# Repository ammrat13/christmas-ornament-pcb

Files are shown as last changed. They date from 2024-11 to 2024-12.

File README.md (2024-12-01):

# EE 256 Final Project: Christmas Ornament

Board files and firmware for my final project for EE 256. I made a relatively
simple project - just a smart christmas ornament.

  * Low-light conditions turn on the LEDs
  * Shaking the ornament flashes the NeoPixels
  * Thresholds and flash parameters configurable via micro-SD card
  * Sensor values, activation statistics, and device health visible over
    Bluetooth LE
  * Supports LiIon batteries
  * Watchdog timer for reliability

## Block Diagram

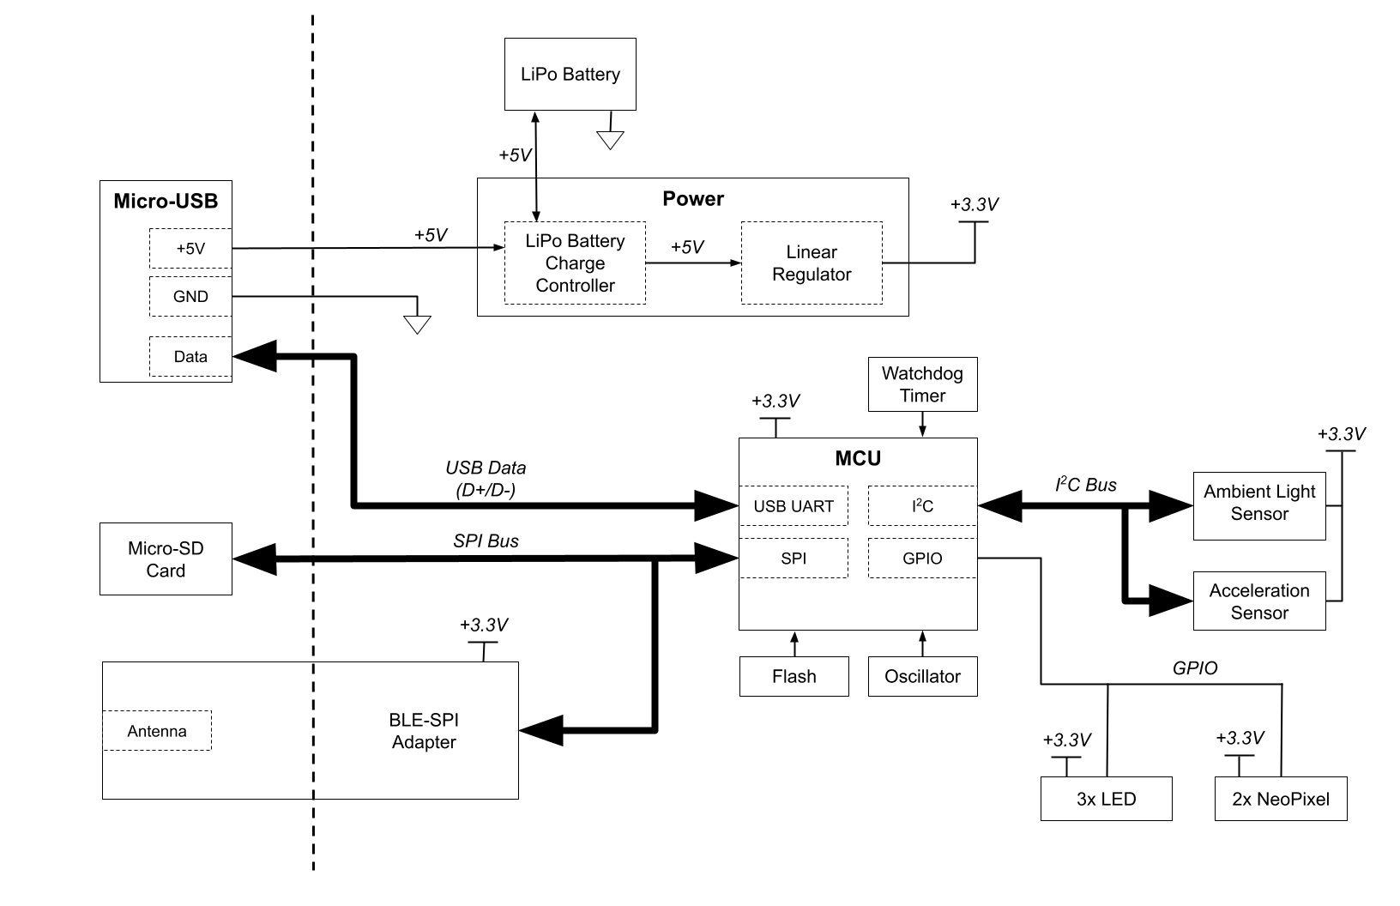
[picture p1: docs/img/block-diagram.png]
Block Diagram


## Project Structure
  * `firmware`: code for the MCU
  * `host`: code to communicate with the MCU over Bluetooth LE
  * `kicad`: board files
  * `kicad-lib`: global library files referenced by the board files

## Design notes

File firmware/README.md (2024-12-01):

# Device Firmware

This folder has the CircuitPython firmware for the device. It contains a
`Pipfile` for installing `circup` on the host, as well as a `requirements.txt`
for getting the required libraries onto the device.

To save on space, all the files (except for `code.py`) are compiled. Download
`mpy-cross` and set the `MPY_CROSS` environment variable to that path. If more
files are added, modify `PY_FILES` in the `Makefile` with the new code. Finally,
mount the device at some path `${DEVICE_PATH}` and run
```
$ make all
$ make PREFIX="${DEVICE_PATH}" install
```

## Configuration Files

An example configuration file is given in `config.txt`. It should be placed at
the root of the micro-SD card. Additionally, if a file named `reset-ble` is
present on the root of the micro-SD card, then the Bluefruit LE SPI friend will
be factory-reset and repopulated.

## Register Map

Over Bluetooth LE, this firmware provides a service with some characteristics,
which act as MMIO registers. The registers are defined in `ble.py` as `CHAR_*`.
The service's UUID is given as `SERVICE_UUID`.

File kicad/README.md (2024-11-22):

# PCB Files

This folder has the KiCad files for the PCBs fabricated. The ADXL 343 Adapter
and Revision 1 of the Project were fabricated. The files in the `kicad-lib`
folder may be needed to edit these files.

## Errata

### Project Revision 1
  * Q1 uses the incorrect footprint. They should be rotated 120 degrees
    counter-clockwise.
  * D2 and D3 don't have decoupling capacitors. They should have 1uF capacitors.
  * D2 doesn't have a decoupling resistor on the data line. It should have a
    470R on the input.

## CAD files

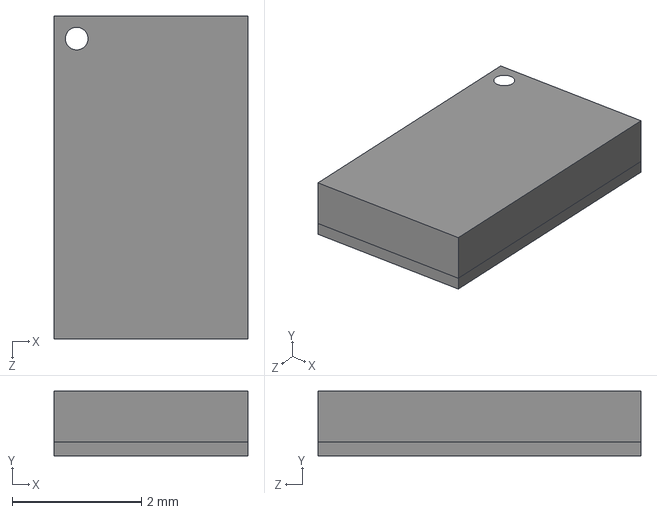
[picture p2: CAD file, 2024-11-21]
kicad/ADXL 343 Adapter/ADXL343BCCZ-RL7.step
3.00 x 1.00 x 5.00 mm

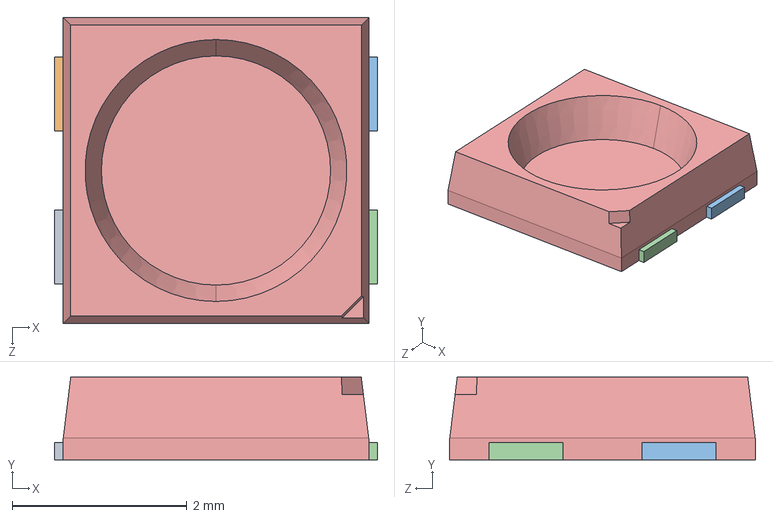
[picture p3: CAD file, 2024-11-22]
kicad/Project/rev2/Components/2659.step
3.70 x 0.95 x 3.50 mm

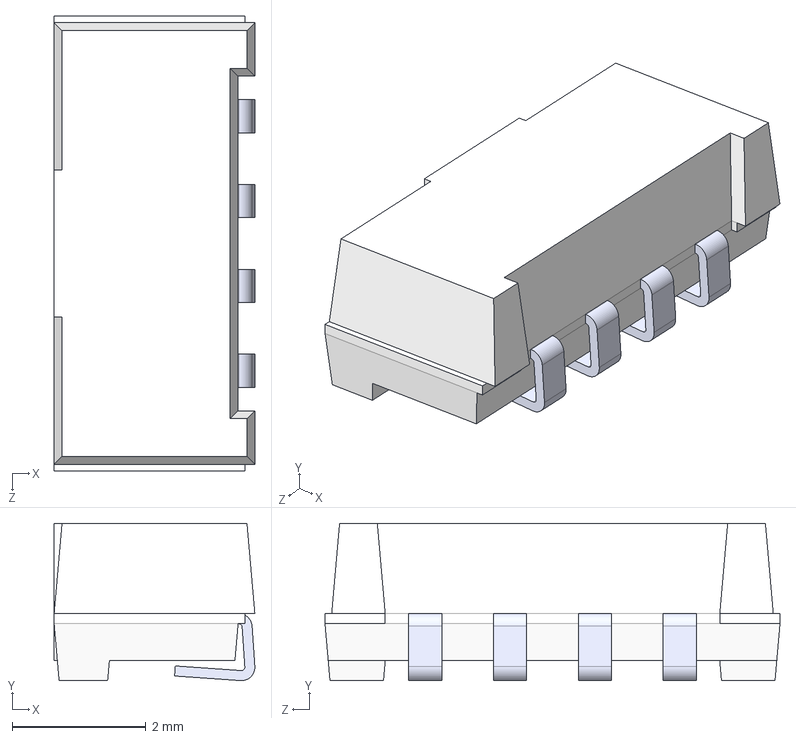
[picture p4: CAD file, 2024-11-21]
kicad/Project/rev2/Components/VEML7700-TR.step
3.00 x 2.35 x 6.80 mm

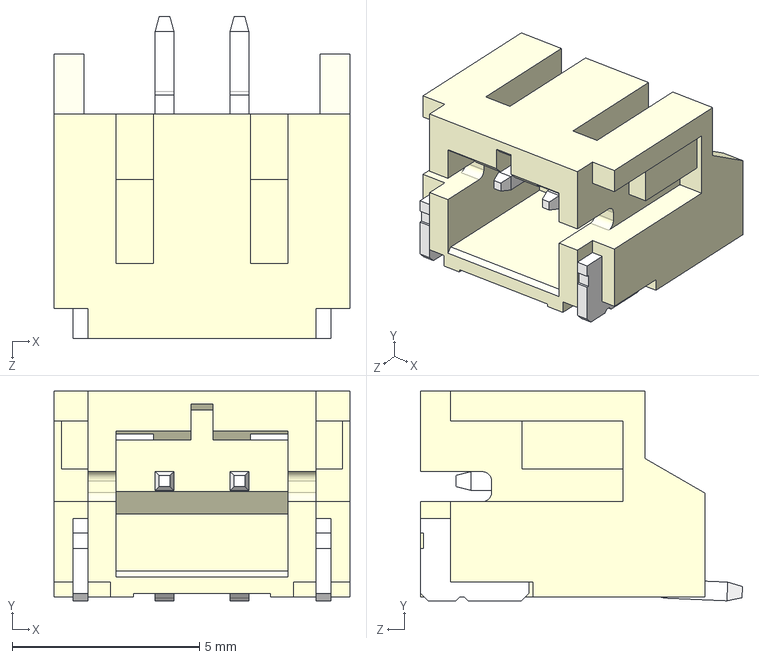
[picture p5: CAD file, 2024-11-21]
kicad/Project/rev2/Components/S2B-PH-SM4-TB.step
7.90 x 5.60 x 8.60 mm

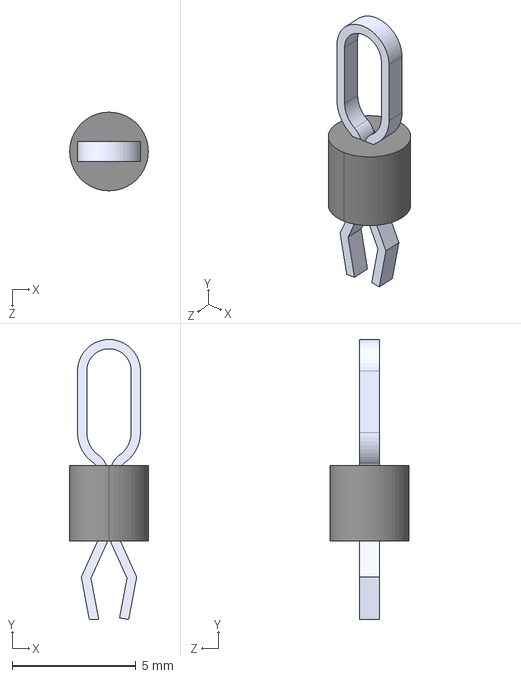
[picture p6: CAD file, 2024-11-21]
kicad/Project/rev2/Components/5011.step
3.17 x 11.3 x 3.17 mm

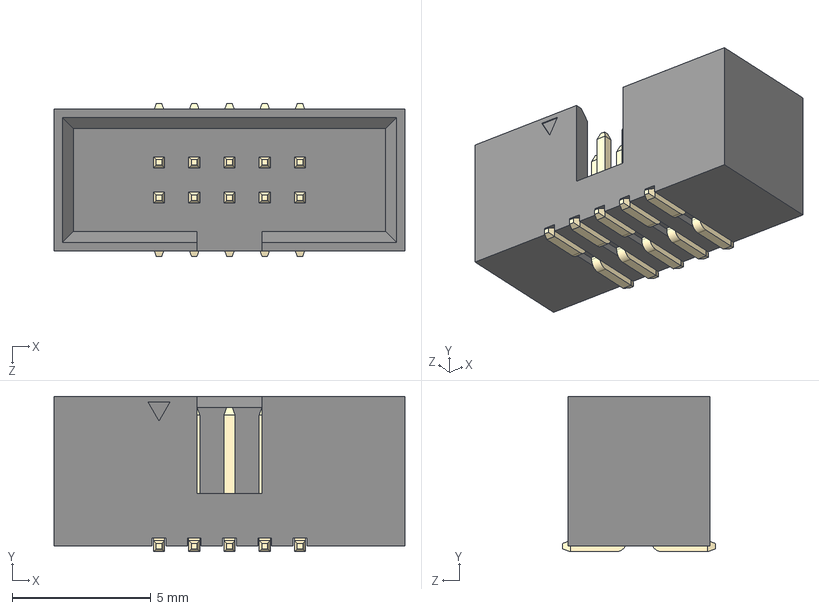
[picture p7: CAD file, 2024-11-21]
kicad/Project/rev2/Components/3220-10-0300-00.step
12.7 x 5.60 x 5.50 mm
3220-xx-0300-00 body_10
Pin^3220-xx-0300-00 x 5
MirrorPin^3220-xx-0300-00 x 5

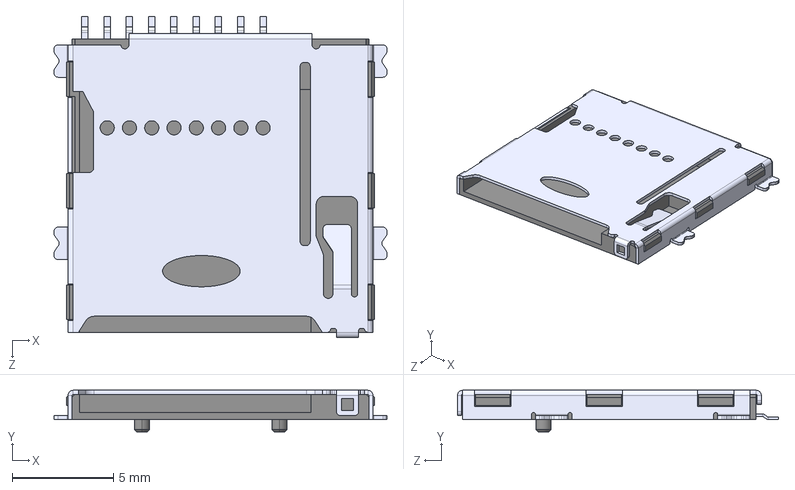
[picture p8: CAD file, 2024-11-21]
kicad/Project/rev2/Components/MEM2075-00-140-01-A.step
16.4 x 2.05 x 15.9 mm

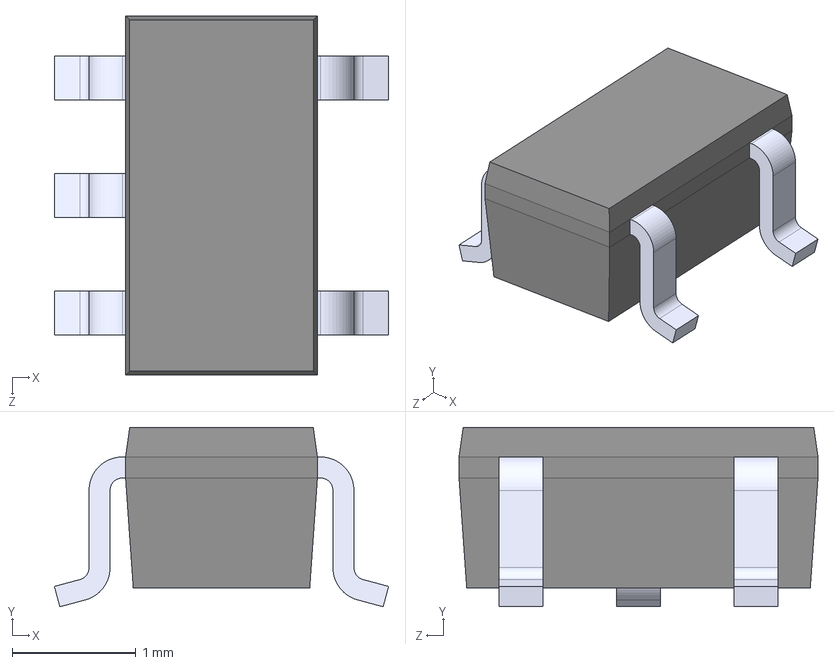
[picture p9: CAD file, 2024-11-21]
kicad/Project/rev2/Components/MCP73831T-2ATI_OT.step
2.70 x 1.45 x 2.90 mm

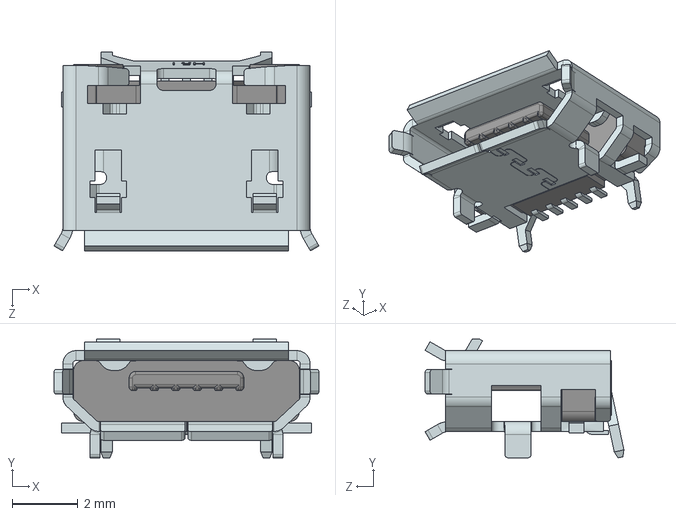
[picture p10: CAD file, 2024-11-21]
kicad/Project/rev2/Components/10103594-0001LF.step
8.04 x 3.60 x 6.03 mm

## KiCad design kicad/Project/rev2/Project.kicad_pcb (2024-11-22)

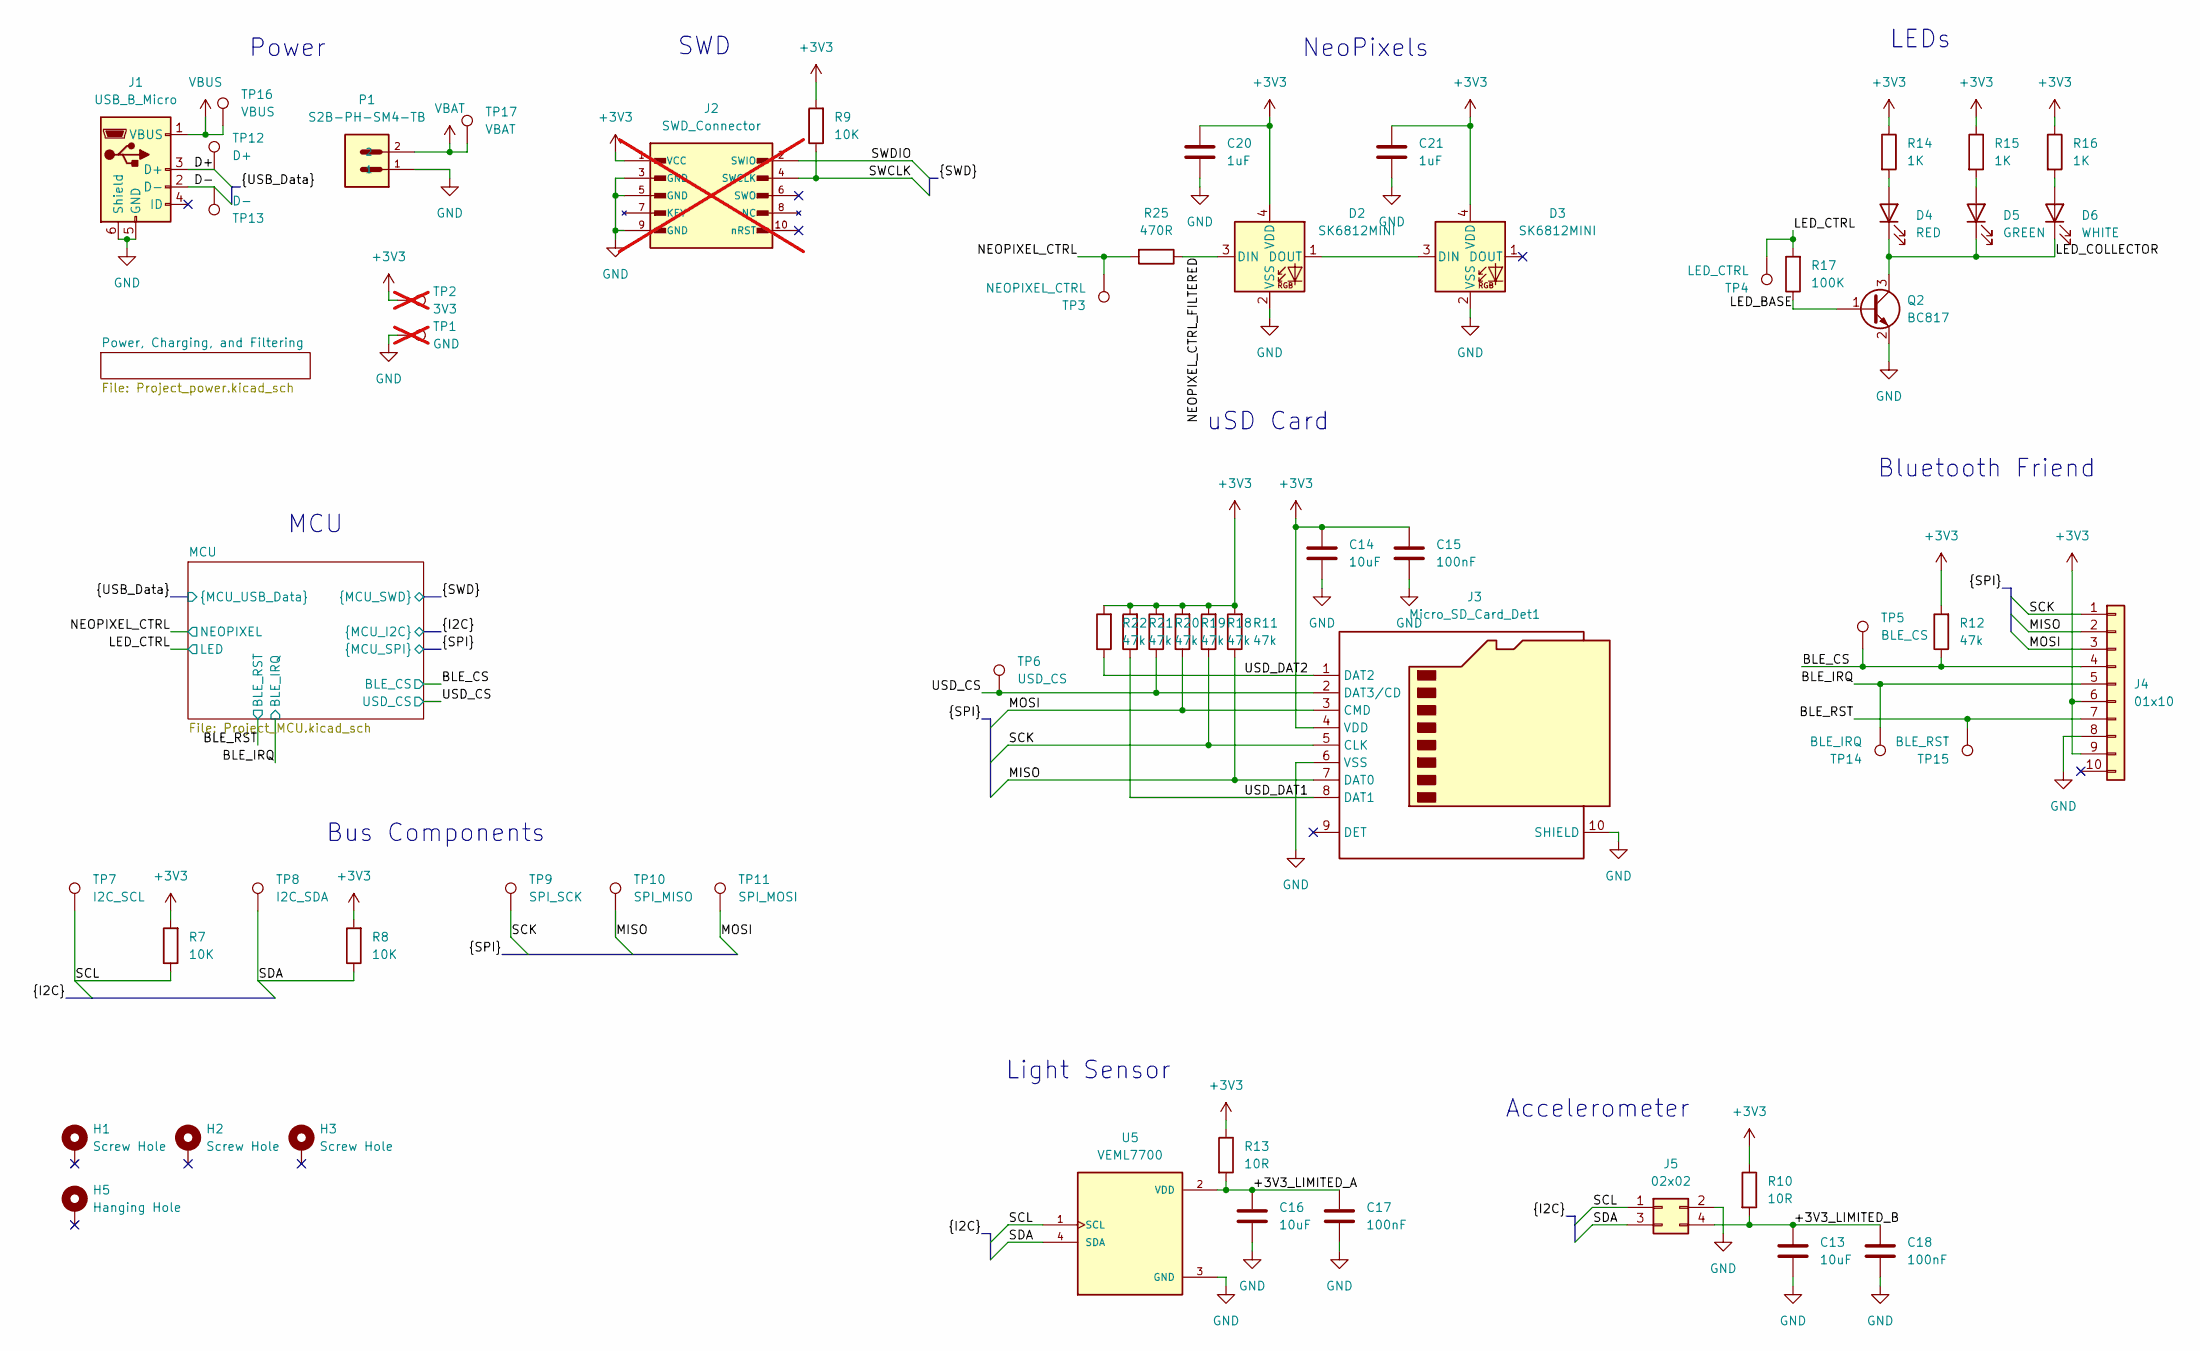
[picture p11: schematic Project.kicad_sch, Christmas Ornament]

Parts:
C13, C14, C16: 10uF; C_0805_2012Metric_Pad1.18x1.45mm_HandSolder; Mfr P/N CL21A106KOQNNNE
C15, C17, C18: 100nF; C_0402_1005Metric_Pad0.74x0.62mm_HandSolder; Mfr P/N CL05B104KP5NNNC
C20, C21: 1uF; C_0603_1608Metric_Pad1.08x0.95mm_HandSolder; Mfr P/N CC0603KRX7R7BB105
D2, D3: SK6812MINI; LED_SK6812MINI_PLCC4_3.5x3.5mm_P1.75mm; Mfr P/N 2659
D4: RED; LED_0805_2012Metric_Pad1.15x1.40mm_HandSolder; Mfr P/N LTST-S220KRKT
D5: GREEN; LED_0805_2012Metric_Pad1.15x1.40mm_HandSolder; Mfr P/N LTST-S220KGKT
D6: WHITE; LED_0805_2012Metric_Pad1.15x1.40mm_HandSolder; Mfr P/N LTW-170TK
H1, H2, H3: Screw Hole; MountingHole_3.2mm_M3_DIN965_Pad_TopBottom
H5: Hanging Hole; MountingHole_3.2mm_M3_DIN965_Pad_TopBottom
J1: USB_B_Micro; USB_Micro-B_Amphenol_10103594-0001LF_Horizontal; Mfr P/N 10103594-0001LF
J2: SWD_Connector; CNC_3220-10-0300-00; Mfr P/N 3220-10-0300-00; not fitted
J3: Micro_SD_Card_Det1; GCT_MEM2075-00-140-01-A; Mfr P/N MEM2075-00-140-01-A
J4: 01x10; PinSocket_1x10_P2.54mm_Vertical; Mfr P/N PPTC101LFBN-RC
J5: 02x02; PinSocket_2x02_P2.54mm_Vertical; Mfr P/N PPPC022LFBN-RC
P1: S2B-PH-SM4-TB; JST_PH_S2B-PH-SM4-TB_1x02-1MP_P2.00mm_Horizontal; Mfr P/N S2B-PH-SM4-TB
Q2: BC817; SOT-23; Mfr P/N BC817-25LT1G
R7, R8, R9: 10K; R_0603_1608Metric_Pad0.98x0.95mm_HandSolder; Mfr P/N RNCP0603FTD10K0
R10, R13: 10R; R_0603_1608Metric_Pad0.98x0.95mm_HandSolder; Mfr P/N RMCF0603FT10R0
R11, R12, R18, R19, R20, R21, R22: 47k; R_0603_1608Metric_Pad0.98x0.95mm_HandSolder; Mfr P/N RC0603FR-0747KL
R14, R15, R16: 1K; R_0603_1608Metric_Pad0.98x0.95mm_HandSolder; Mfr P/N MCT06030C1001FP500
R17: 100K; R_0603_1608Metric_Pad0.98x0.95mm_HandSolder; Mfr P/N RMCF0603FT100K
R25: 470R; R_0603_1608Metric_Pad0.98x0.95mm_HandSolder; Mfr P/N RC0603JR-07470RL
TP1: GND; TP_5011; Mfr P/N 5011; not fitted
TP2: 3V3; TP_5011; Mfr P/N 5010; not fitted
TP3: NEOPIXEL_CTRL; TestPoint_Pad_D2.0mm
TP4: LED_CTRL; TestPoint_Pad_D2.0mm
TP5: BLE_CS; TestPoint_Pad_D2.0mm
TP6: USD_CS; TestPoint_Pad_D2.0mm
TP7: I2C_SCL; TestPoint_Pad_D2.0mm
TP8: I2C_SDA; TestPoint_Pad_D2.0mm
TP9: SPI_SCK; TestPoint_Pad_D2.0mm
TP10: SPI_MISO; TestPoint_Pad_D2.0mm
TP11: SPI_MOSI; TestPoint_Pad_D2.0mm
TP12: D+; TestPoint_Pad_D2.0mm
TP13: D-; TestPoint_Pad_D2.0mm
TP14: BLE_IRQ; TestPoint_Pad_D2.0mm
TP15: BLE_RST; TestPoint_Pad_D2.0mm
TP16: VBUS; TestPoint_Pad_D2.0mm
TP17: VBAT; TestPoint_Pad_D2.0mm
U5: VEML7700; XDCR_VEML7700-TR; Mfr P/N VEML7700-TR

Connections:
+3V3: C14.1, C15.1, C20.1, C21.1, D2.4 (VDD), D3.4 (VDD), J2.1 (VCC), J3.4 (VDD), J4.6, J4.9, R7.2, R8.2, R9.2, R10.1, R11.2, R12.2, R13.1, R14.1, R15.1, R16.1, R18.2, R19.2, R20.2, R21.2, R22.2, TP2.1; also elsewhere on the board
/+3V3_LIMITED_A: C16.1, C17.1, R13.2, U5.2 (VDD)
/+3V3_LIMITED_B: C13.1, C18.1, J5.4, R10.2
/BLE_CS: J4.4, R12.1, TP5.1; also elsewhere on the board
/BLE_IRQ: J4.5, TP14.1; also elsewhere on the board
/BLE_RST: J4.7, TP15.1; also elsewhere on the board
/D+: J1.3 (D+), TP12.1; also elsewhere on the board
/D-: J1.2 (D-), TP13.1; also elsewhere on the board
/LED_BASE: Q2.1 (B), R17.1
/LED_COLLECTOR: D4.1 (K), D5.1 (K), D6.1 (K), Q2.3 (C)
/LED_CTRL: R17.2, TP4.1; also elsewhere on the board
/MISO: J3.7 (DAT0), J4.2, R11.1, TP10.1; also elsewhere on the board
/MOSI: J3.3 (CMD), J4.3, R19.1, TP11.1; also elsewhere on the board
/NEOPIXEL_CTRL: R25.2, TP3.1; also elsewhere on the board
/NEOPIXEL_CTRL_FILTERED: D2.3 (DIN), R25.1
/SCK: J3.5 (CLK), J4.1, R18.1, TP9.1; also elsewhere on the board
/SCL: J5.1, R7.1, TP7.1, U5.1 (SCL); also elsewhere on the board
/SDA: J5.3, R8.1, TP8.1, U5.4 (SDA); also elsewhere on the board
/SWCLK: J2.4 (SWCLK), R9.1; also elsewhere on the board
/SWDIO: J2.2 (SWIO); also elsewhere on the board
/USD_CS: J3.2 (DAT3/CD), R20.1, TP6.1; also elsewhere on the board
/USD_DAT1: J3.8 (DAT1), R21.1
/USD_DAT2: J3.1 (DAT2), R22.1
GND: C13.2, C14.2, C15.2, C16.2, C17.2, C18.2, C20.2, C21.2, D2.2 (VSS), D3.2 (VSS), J1.5 (GND), J1.6 (Shield), J2.3 (GND), J2.5 (GND), J2.9 (GND), J3.6 (VSS), J3.10 (SHIELD), J4.8, J5.2, P1.1, Q2.2 (E), TP1.1, U5.3 (GND); also elsewhere on the board
unnamed: D2.1 (DOUT), D3.3 (DIN)
unnamed: D4.2 (A), R14.2
unnamed: D5.2 (A), R15.2
unnamed: D6.2 (A), R16.2
VBAT: P1.2, TP17.1; also elsewhere on the board
VBUS: J1.1 (VBUS), TP16.1; also elsewhere on the board

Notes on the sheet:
MCU
Accelerometer
Bus Components
Bluetooth Friend
SWD
Light Sensor
NeoPixels
uSD Card
LEDs
Power

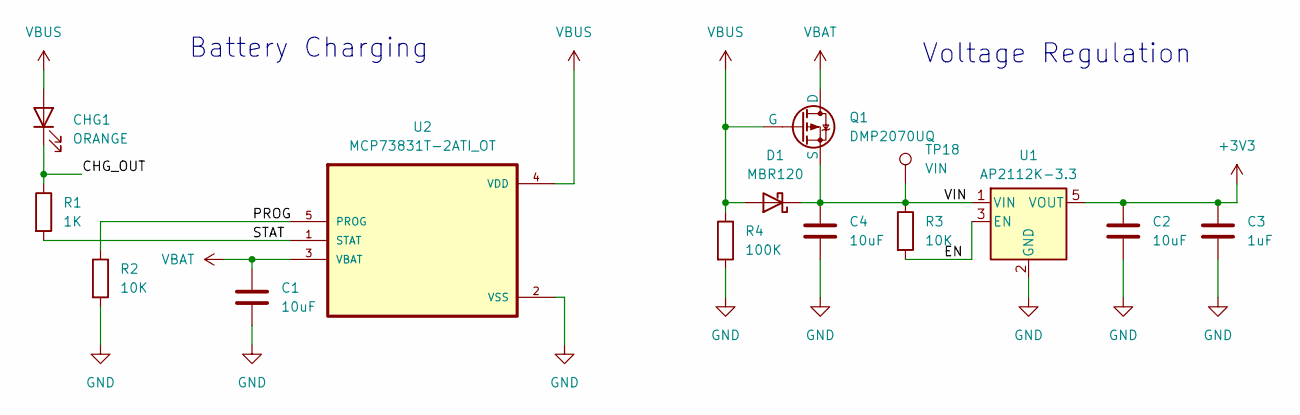
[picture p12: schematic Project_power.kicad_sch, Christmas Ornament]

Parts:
C1, C2, C4: 10uF; C_0805_2012Metric_Pad1.18x1.45mm_HandSolder; Mfr P/N CL21A106KOQNNNE
C3: 1uF; C_0603_1608Metric_Pad1.08x0.95mm_HandSolder; Mfr P/N CC0603KRX7R7BB105
CHG1: ORANGE; LED_0805_2012Metric_Pad1.15x1.40mm_HandSolder; Mfr P/N B1701UD--20D000414U1930
D1: MBR120; D_SOD-123; Mfr P/N MBR120LSFT1G
Q1: DMP2070UQ; SOT-23_Handsoldering
R1: 1K; R_0603_1608Metric_Pad0.98x0.95mm_HandSolder; Mfr P/N MCT06030C1001FP500
R2, R3: 10K; R_0603_1608Metric_Pad0.98x0.95mm_HandSolder; Mfr P/N RNCP0603FTD10K0
R4: 100K; R_0603_1608Metric_Pad0.98x0.95mm_HandSolder; Mfr P/N RMCF0603FT100K
TP18: VIN; TestPoint_Pad_D2.0mm
U1: AP2112K-3.3; SOT-23-5
U2: MCP73831T-2ATI_OT; SOT-23-5_HandSoldering; Mfr P/N MCP73831T-2ATI/OT

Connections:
+3V3: C2.1, C3.1, U1.5 (VOUT); also elsewhere on the board
/Power, Charging, and Filtering/CHG_OUT: CHG1.1 (K), R1.1
/Power, Charging, and Filtering/EN: R3.2, U1.3 (EN)
/Power, Charging, and Filtering/PROG: R2.1, U2.5 (PROG)
/Power, Charging, and Filtering/STAT: R1.2, U2.1 (STAT)
/Power, Charging, and Filtering/VIN: C4.1, D1.1 (K), Q1.2 (S), R3.1, TP18.1, U1.1 (VIN)
GND: C1.2, C2.2, C3.2, C4.2, R2.2, R4.2, U1.2 (GND), U2.2 (VSS); also elsewhere on the board
VBAT: C1.1, Q1.3 (D), U2.3 (VBAT); also elsewhere on the board
VBUS: CHG1.2 (A), D1.2 (A), Q1.1 (G), R4.1, U2.4 (VDD); also elsewhere on the board

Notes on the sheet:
Battery Charging
Voltage Regulation

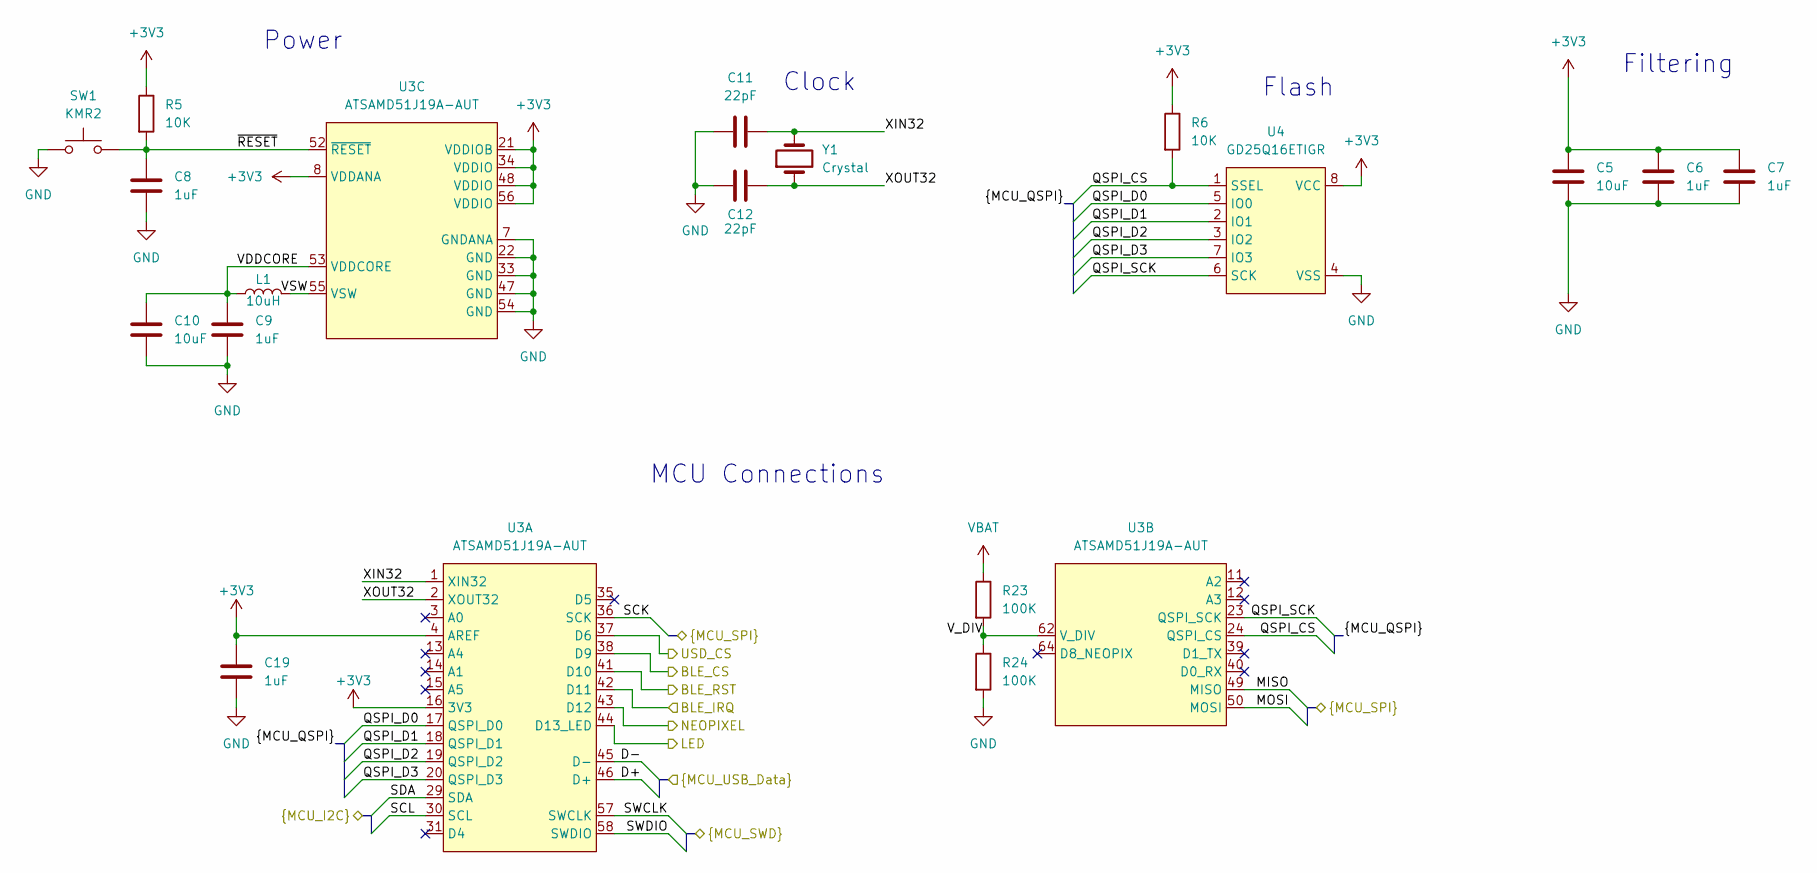
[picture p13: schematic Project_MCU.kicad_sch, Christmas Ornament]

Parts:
C5, C10: 10uF; C_0805_2012Metric_Pad1.18x1.45mm_HandSolder; Mfr P/N CL21A106KOQNNNE
C6, C7, C8, C9, C19: 1uF; C_0603_1608Metric_Pad1.08x0.95mm_HandSolder; Mfr P/N CC0603KRX7R7BB105
C11, C12: 22pF; C_0603_1608Metric_Pad1.08x0.95mm_HandSolder; Mfr P/N C0603C220K4GAC7867
L1: 10uH; L_1008_2520Metric; Mfr P/N LSQEA251818T100K
R5, R6: 10K; R_0603_1608Metric_Pad0.98x0.95mm_HandSolder; Mfr P/N RNCP0603FTD10K0
R23, R24: 100K; R_0603_1608Metric_Pad0.98x0.95mm_HandSolder; Mfr P/N RMCF0603FT100K
SW1: KMR2; SW_Push_1P1T_NO_CK_KMR2; Mfr P/N KMR241NG ULC LFS
U3: ATSAMD51J19A-AUT; TQFP-64_10x10mm_P0.5mm; Mfr P/N ATSAMD51J19A-AUT
U4: GD25Q16ETIGR; SOIC-8_3.9x4.9mm_P1.27mm; Mfr P/N GD25Q16ETIGR
Y1: Crystal; XTAL3215; Mfr P/N STDMUA17-32.768K

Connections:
+3V3: C5.1, C6.1, C7.1, C19.1, R5.1, R6.1, U3.4 (AREF), U3.8 (VDDANA), U3.16 (3V3), U3.21 (VDDIOB), U3.34 (VDDIO), U3.48 (VDDIO), U3.56 (VDDIO), U4.8 (VCC); also elsewhere on the board
/BLE_CS: U3.38 (D9); also elsewhere on the board
/BLE_IRQ: U3.42 (D11); also elsewhere on the board
/BLE_RST: U3.41 (D10); also elsewhere on the board
/D+: U3.46 (D+); also elsewhere on the board
/D-: U3.45 (D-); also elsewhere on the board
/LED_CTRL: U3.44 (D13_LED); also elsewhere on the board
/MCU/QSPI_CS: R6.2, U3.24 (QSPI_CS), U4.1 (SSEL)
/MCU/QSPI_D0: U3.17 (QSPI_D0), U4.5 (IO0)
/MCU/QSPI_D1: U3.18 (QSPI_D1), U4.2 (IO1)
/MCU/QSPI_D2: U3.19 (QSPI_D2), U4.3 (IO2)
/MCU/QSPI_D3: U3.20 (QSPI_D3), U4.7 (IO3)
/MCU/QSPI_SCK: U3.23 (QSPI_SCK), U4.6 (SCK)
/MCU/VDDCORE: C9.1, C10.1, L1.1, U3.53 (VDDCORE)
/MCU/VSW: L1.2, U3.55 (VSW)
/MCU/V_DIV: R23.2, R24.1, U3.62 (V_DIV)
/MCU/XIN32: C11.1, U3.1 (XIN32), Y1.2
/MCU/XOUT32: C12.1, U3.2 (XOUT32), Y1.1
/MCU/~RESET: C8.1, R5.2, SW1.2, U3.52 (~RESET)
/MISO: U3.49 (MISO); also elsewhere on the board
/MOSI: U3.50 (MOSI); also elsewhere on the board
/NEOPIXEL_CTRL: U3.43 (D12); also elsewhere on the board
/SCK: U3.36 (SCK); also elsewhere on the board
/SCL: U3.30 (SCL); also elsewhere on the board
/SDA: U3.29 (SDA); also elsewhere on the board
/SWCLK: U3.57 (SWCLK); also elsewhere on the board
/SWDIO: U3.58 (SWDIO); also elsewhere on the board
/USD_CS: U3.37 (D6); also elsewhere on the board
GND: C5.2, C6.2, C7.2, C8.2, C9.2, C10.2, C11.2, C12.2, C19.2, R24.2, SW1.1, U3.7 (GNDANA), U3.22 (GND), U3.33 (GND), U3.47 (GND), U3.54 (GND), U4.4 (VSS); also elsewhere on the board
VBAT: R23.1; also elsewhere on the board

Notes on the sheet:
Power
Filtering
Clock
MCU Connections
Flash

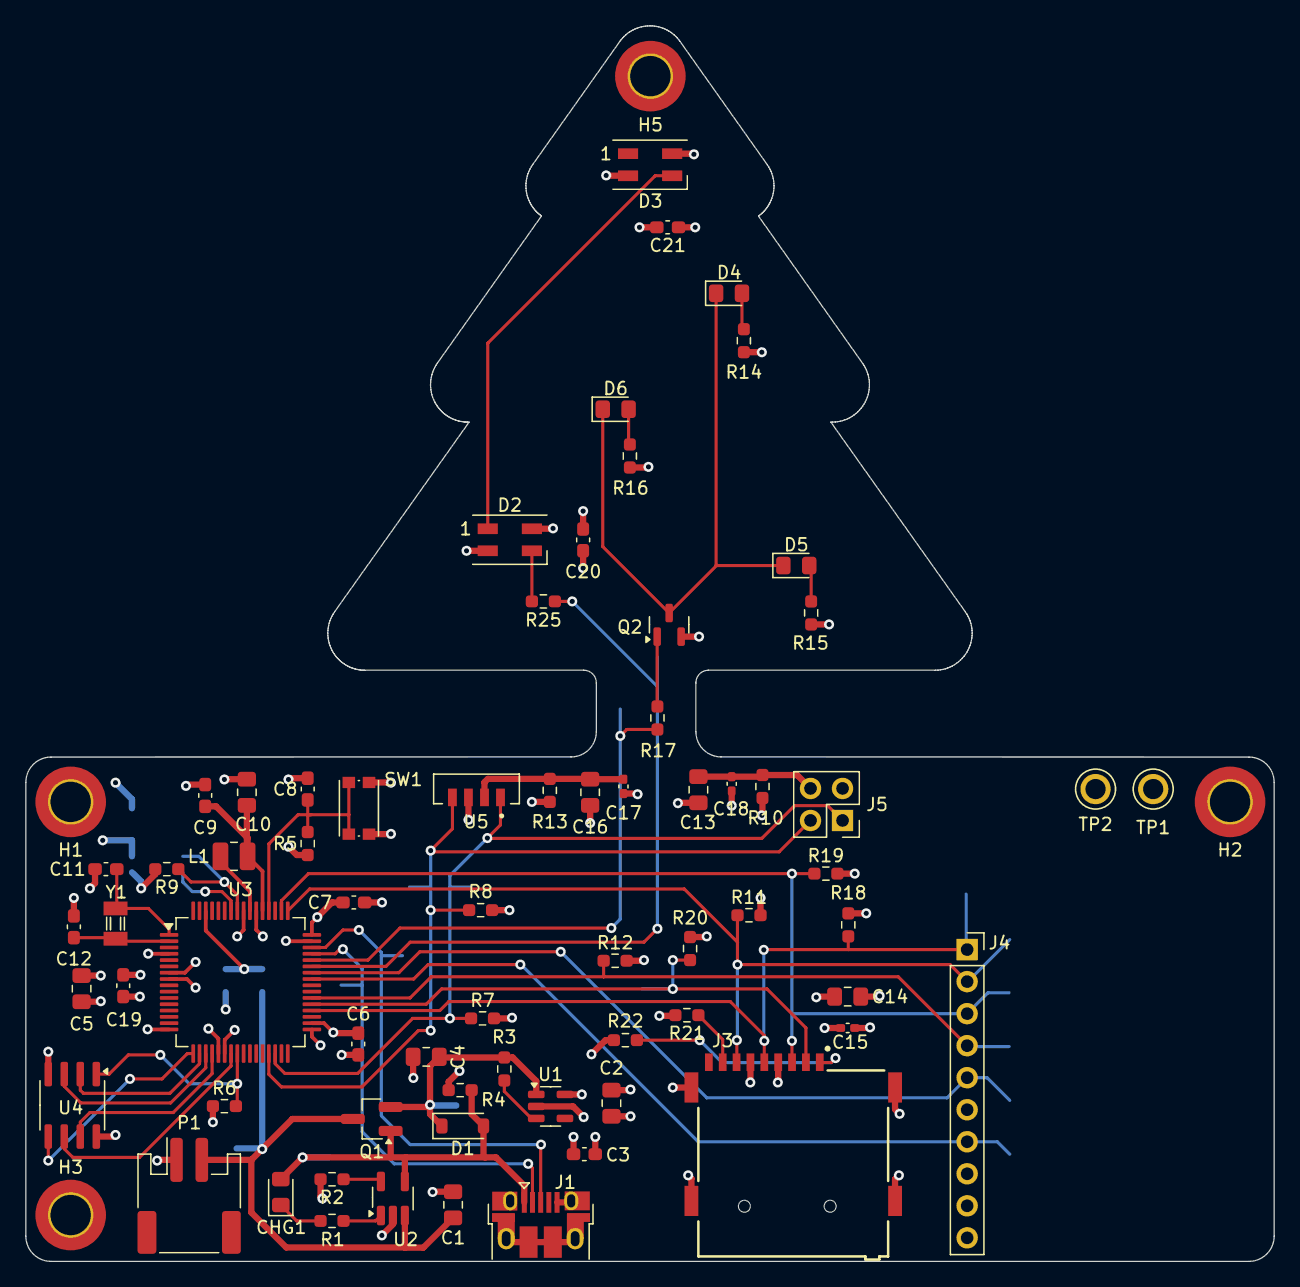
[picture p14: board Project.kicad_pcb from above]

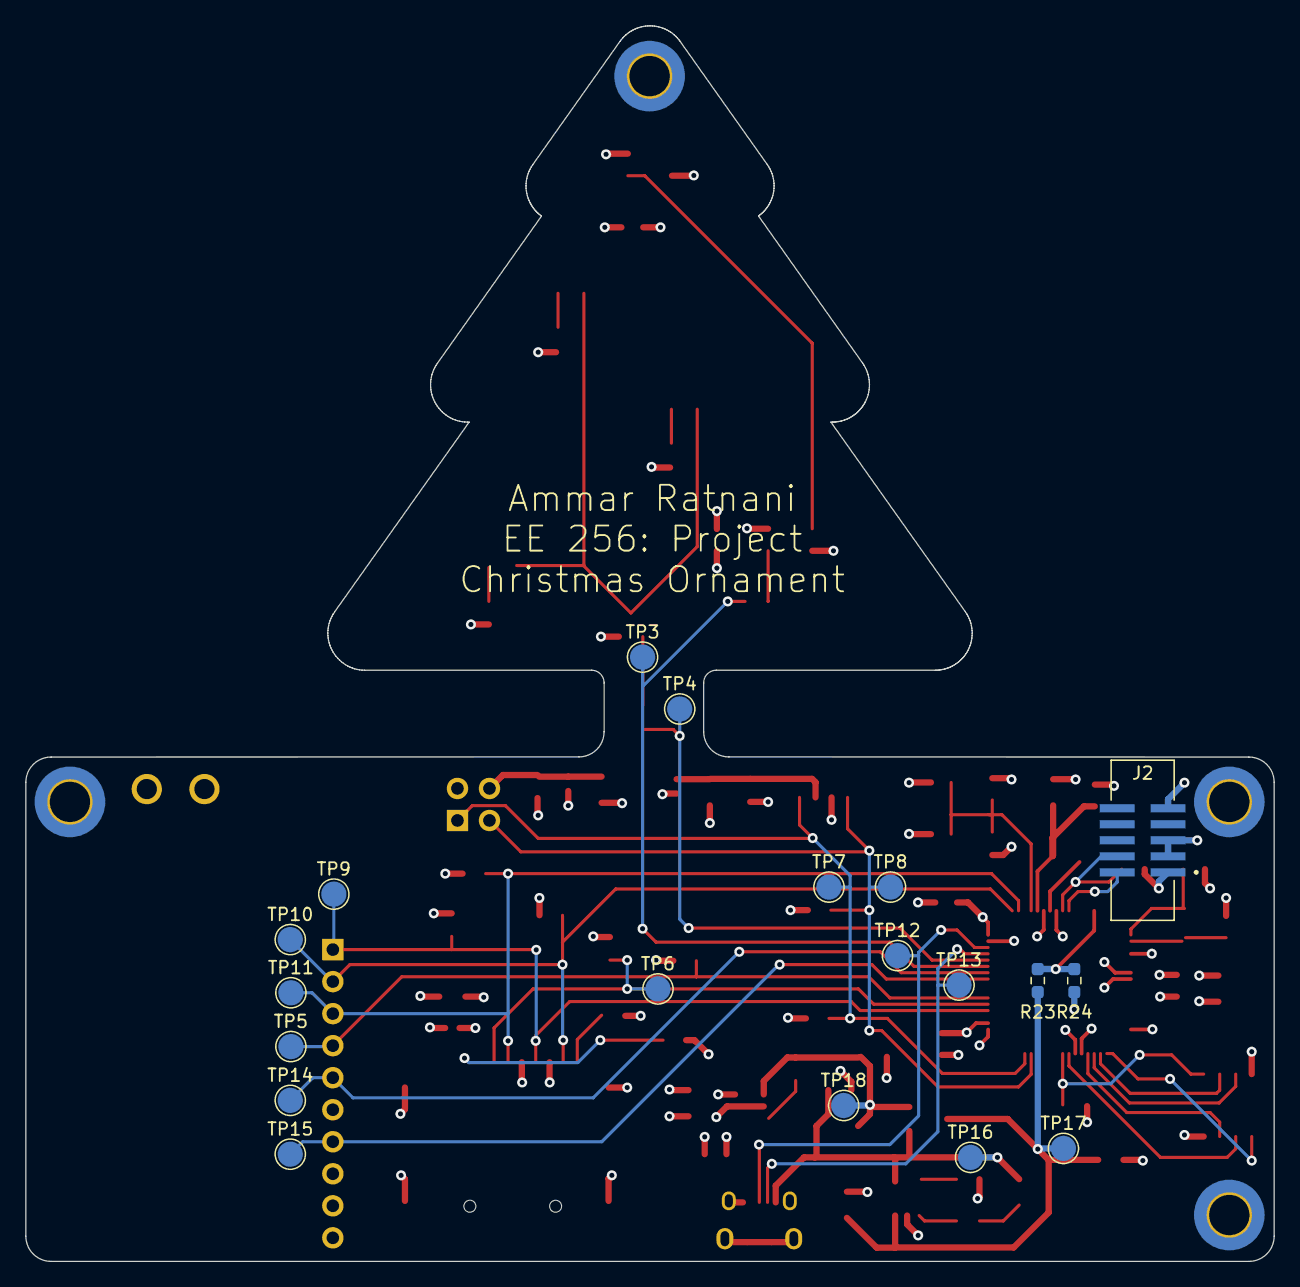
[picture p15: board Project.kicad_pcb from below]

Board: 4 copper layers, 99.0 x 98.0 mm, 91 parts (19 on the bottom side), 47 nets.

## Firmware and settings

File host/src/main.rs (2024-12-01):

mod attrs;
mod ble;

use std::time::Duration;

use anyhow::{Context, Error, Result};
use argparse::ArgumentParser;
use btleplug::api::Peripheral as _;
use btleplug::platform::Peripheral;
use tokio::net::TcpListener;
use tokio::task::JoinSet;

use attrs::ApplicationState;

#[tokio::main]
async fn main() -> Result<()> {
    env_logger::init();

    let mut local_name = String::from("Christmas Ornament");
    let mut scan_time_s = 15u64;
    let mut disconnect_poll_s = 1u64;
    let mut port = 3000u16;
    {
        let mut ap = ArgumentParser::new();
        ap.set_description("Interface with the Christmas ornament over BLE");
        ap.refer(&mut scan_time_s).metavar("SCAN_TIME").add_option(
            &["-t", "--scan-time"],
            argparse::Store,
            "Time to scan for peripherals for, in seconds",
        );
        ap.refer(&mut disconnect_poll_s)
            .metavar("DISCONNECT_POLL_INTERVAL")
            .add_option(
                &["-d", "--disconnect-poll"],
                argparse::Store,
                "Time to poll for the ornament disconnecting, in seconds",
            );
        ap.refer(&mut port).metavar("PORT").add_option(
            &["-p", "--port"],
            argparse::Store,
            "Port to listen on for HTTP requests",
        );
        ap.refer(&mut local_name)
            .metavar("LOCAL_NAME")
            .required()
            .add_argument(
                "local_name",
                argparse::Store,
                "Display name of the ornament",
            );
        ap.parse_args_or_exit();
    }

    let scan_duration = Duration::from_secs(scan_time_s);
    let poll_duration = Duration::from_secs(disconnect_poll_s);

    let peripheral = ble::connect(&local_name, scan_duration).await?;
    let service = ble::get_service(&peripheral)?;

    let app = attrs::router().with_state(ApplicationState {
        peripheral: peripheral.clone(),
        service: service.clone(),
    });

    let listener = TcpListener::bind(("0.0.0.0", port)).await.unwrap();

    let mut joinset = JoinSet::new();
    joinset.spawn(async { axum::serve(listener, app).await.context("Server died") });
    joinset.spawn(disconnect_handler(peripheral.clone(), poll_duration));

    while let Some(r) = joinset.join_next().await {
        let r = match r {
            Ok(r) => r,
            Err(e) => anyhow::bail!("{:?}", e),
        };
        match r {
            Ok(()) => anyhow::bail!("Some task finished when it was supposed to run forever"),
            Err(e) => anyhow::bail!("{:?}", e),
        }
    }

    // We should always pop some result, so this is unreachable
    unreachable!();
}

/// What to do when the peripheral disconnects from us. We'll poll this every
/// second, and cause an error if that happens.
async fn disconnect_handler(peripheral: Peripheral, poll_interval: Duration) -> Result<(), Error> {
    loop {
        tokio::time::sleep(poll_interval).await;
        if peripheral.is_connected().await? {
            continue;
        }
        anyhow::bail!("Peripheral disconnected");
    }
}

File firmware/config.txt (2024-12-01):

################################################################################
#
# Sample configuration file.
#
# Save this as `config.txt` on the root of the micro-SD card.
#
################################################################################

# Name of the device, as shown in Bluetooth scans. Only has an effect once the
# Bluefruit LE SPI module is reset.
DEVICE_NAME = Ammar Ratnani EE 256

# The light level below which the LEDs will be turned on, in lux
LIGHT_THRESHOLD = 30.0
# The exponential moving average factor for the light sensor
LIGHT_MOVING_AVG = 0.8

# The acceleration threshold for detecting acceleration, in g
ACCELERATION_THRESHOLD = 6.25

# The brightness of the NeoPixels when they are flashing, from 0 to 255
NEOPIXEL_BRIGHTNESS = 5
# The time in seconds for the NeoPixels to flash
NEOPIXEL_FLASH_TIME = 1.0
# The number of seconds to wait between frames of flashing
NEOPIXEL_FLASH_SPEED = 0.1

# The time in seconds before the watchdog will reset the device
WATCHDOG_TIMEOUT = 10.0
# The time in seconds between watchdog pets. The task to perform the pet will
# become available after this time, but it may not be run immediately.
WATCHDOG_PET_INTERVAL = 5.0

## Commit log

2024-11-21 Modify title blocks for Rev1
    [Project.kicad_pcb, Project.kicad_sch]
2024-11-21 Push Rev2
    This revision fixes the issue with Q1 in Rev1
    [10103594-0001LF.step, 3220-10-0300-00.step, 5011.step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]
2024-11-22 Add discovered errata
    [Project.kicad_pcb, Project.kicad_sch]
2024-11-22 Use the more common NeoPixels
    [2659.step, Project.kicad_pcb, Project.kicad_sch]
2024-11-28 Add battery monitor
2024-11-29 Copy config over
    [config.txt]
2024-11-30 Add accelerometer count
2024-11-30 Add special case for all `f`s
2024-12-01 Change units for acceleration threshold
    [config.txt]
2024-12-01 Add LED reconfiguration
2024-12-01 Add boot count
    [config.txt]
2024-12-01 Add watchdog parameters
    [config.txt]
2024-12-01 Add device name option
    [config.txt]
